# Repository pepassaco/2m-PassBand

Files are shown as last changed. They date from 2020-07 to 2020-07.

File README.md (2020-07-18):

# Filtro paso banda para 137MHz
Filtro diseñado para trabajar adecuadamente la banda de 2m (VHF). Capaz de cubrir tanto la zona destinada a comunicaciones entre radioaficionados (144MHz-148MHz) como la asociada a los satélites NOAA 15, 18, 19 y Meteor M N2-1 (137MHz-138MHz). 

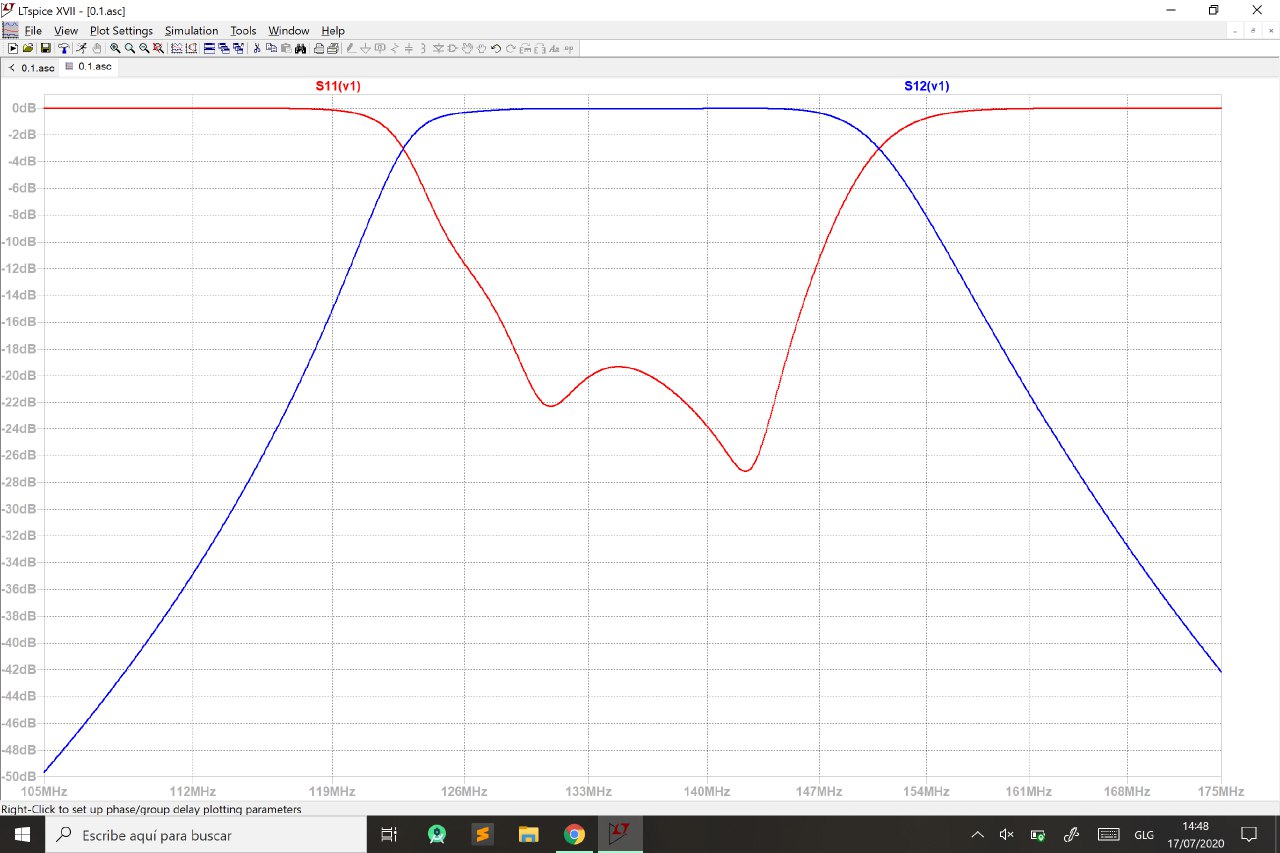
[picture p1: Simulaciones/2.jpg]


# Características:

- Tipo de filtro: paso banda, Butterworth modificado para mejor S11 en banda de paso

- Orden: 6

- Frecuencia de corte inferior: 125MHz

- Frecuencia de corte sueprior: 155MHz

- Atenuación banda radiodifusión FM: >50dB

- Inpedancia de entrada: 50Ω

- Inpedancia de salida: 50Ω

**Note**: on the PCB, the 6th stage of the filter includes space for a second inductor. This es due to the unavailability of an inductor of the esact value I needes, so I ended up dividing it into two that added up the original value.

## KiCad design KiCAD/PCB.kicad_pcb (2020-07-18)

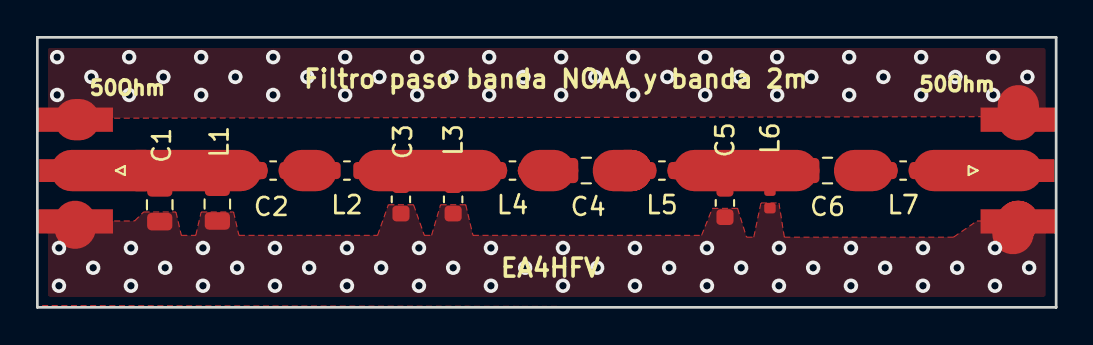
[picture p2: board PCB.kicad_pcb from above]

Board: 2 copper layers, 56.6 x 15.0 mm, 13 parts (0 on the bottom side), 8 nets.

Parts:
C1: 56pF; C_0805_2012Metric
C2: 3,3pF; C_0603_1608Metric
C3: 220pF; C_0603_1608Metric
C4: 2,7pF; C_0805_2012Metric
C5: 150pF; C_0603_1608Metric
C6: 10pF; C_0805_2012Metric
L1: 22nH; L_0805_2012Metric
L2, L4: 390nH; L_0603_1608Metric
L3: 6,2nH; L_0603_1608Metric
L5: 120nH; L_0603_1608Metric
L6: 9,1nH; L_0402_1005Metric
L7: 130nH; L_0603_1608Metric

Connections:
Earth: C1.2, C3.2, C5.2, L1.2, L3.2, L6.2
unnamed: C1.1, C2.2, L1.1
unnamed: C2.1, L2.2
unnamed: C3.1, L2.1, L3.1, L4.2
unnamed: C4.1, L5.2
unnamed: C4.2, L4.1
unnamed: C5.1, C6.2, L5.1, L6.1
unnamed: C6.1, L7.2
